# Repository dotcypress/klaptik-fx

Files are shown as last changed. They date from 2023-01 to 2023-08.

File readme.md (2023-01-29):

# klaptik-fx

Experimental Semigraphics Display.

klaptik-fx

## License

Licensed under either of

- Apache License, Version 2.0 ([LICENSE-APACHE](LICENSE-APACHE) or
  http://www.apache.org/licenses/LICENSE-2.0)
- MIT license ([LICENSE-MIT](LICENSE-MIT) or http://opensource.org/licenses/MIT)

at your option.

### Contribution

Unless you explicitly state otherwise, any contribution intentionally submitted
for inclusion in the work by you, as defined in the Apache-2.0 license, shall be
dual licensed as above, without any additional terms or conditions.

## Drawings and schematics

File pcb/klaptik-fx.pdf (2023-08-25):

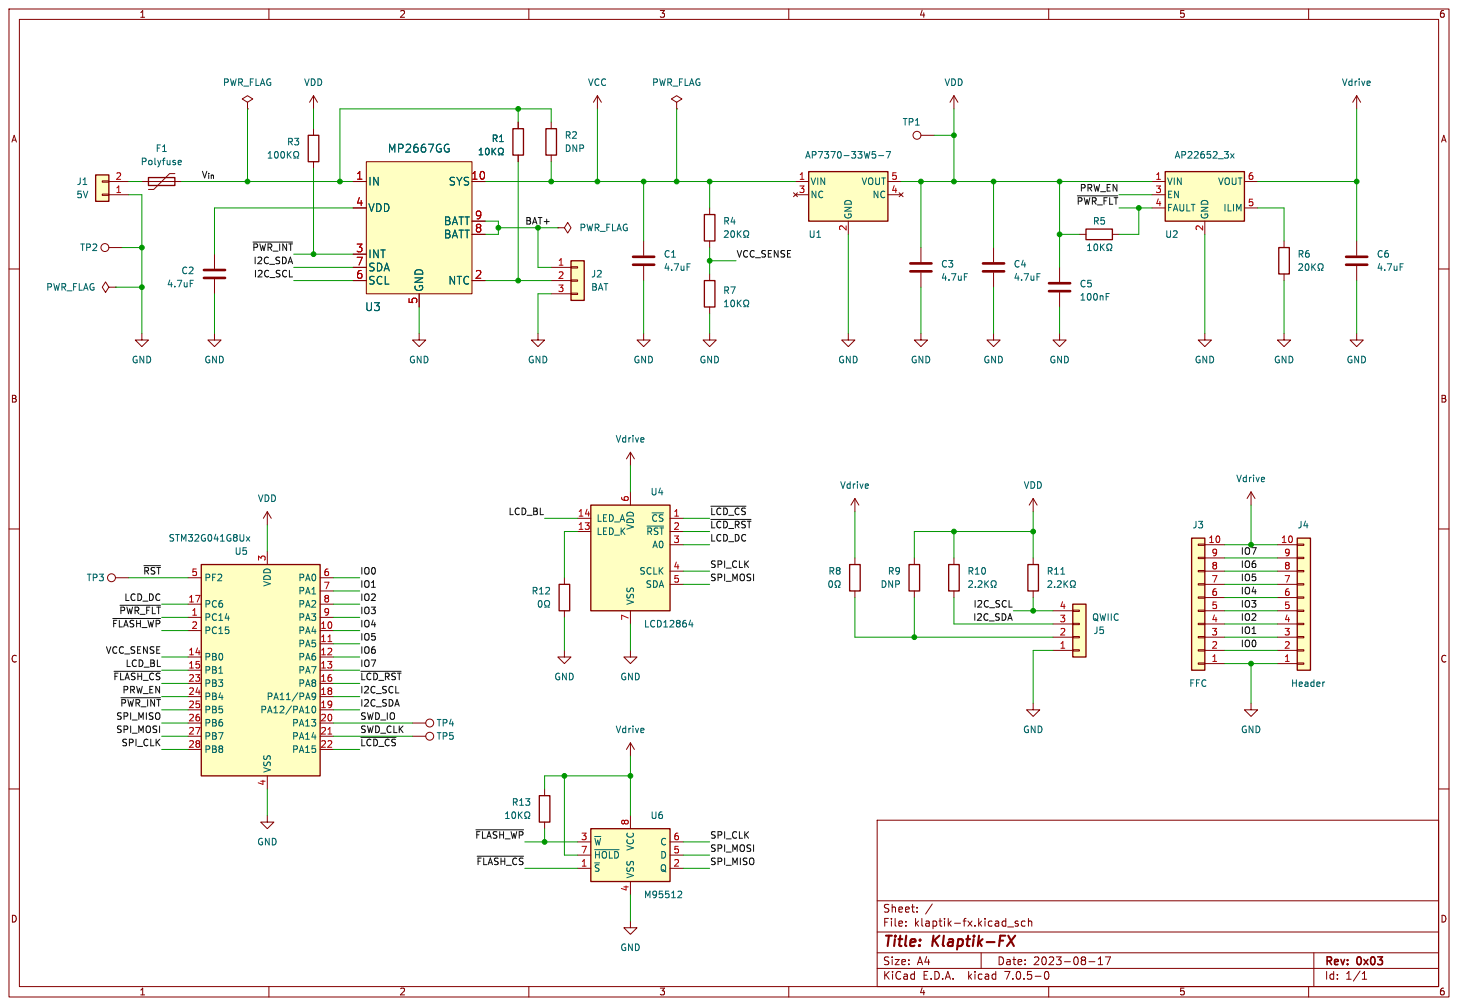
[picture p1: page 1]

5 SCL 6 SDA 7 BATT 8 BATT 9 U3 MP2667GG

5 SCL 6 SDA 7 BATT 8 BATT 9

Id: 1/1 Title: Klaptik-FX

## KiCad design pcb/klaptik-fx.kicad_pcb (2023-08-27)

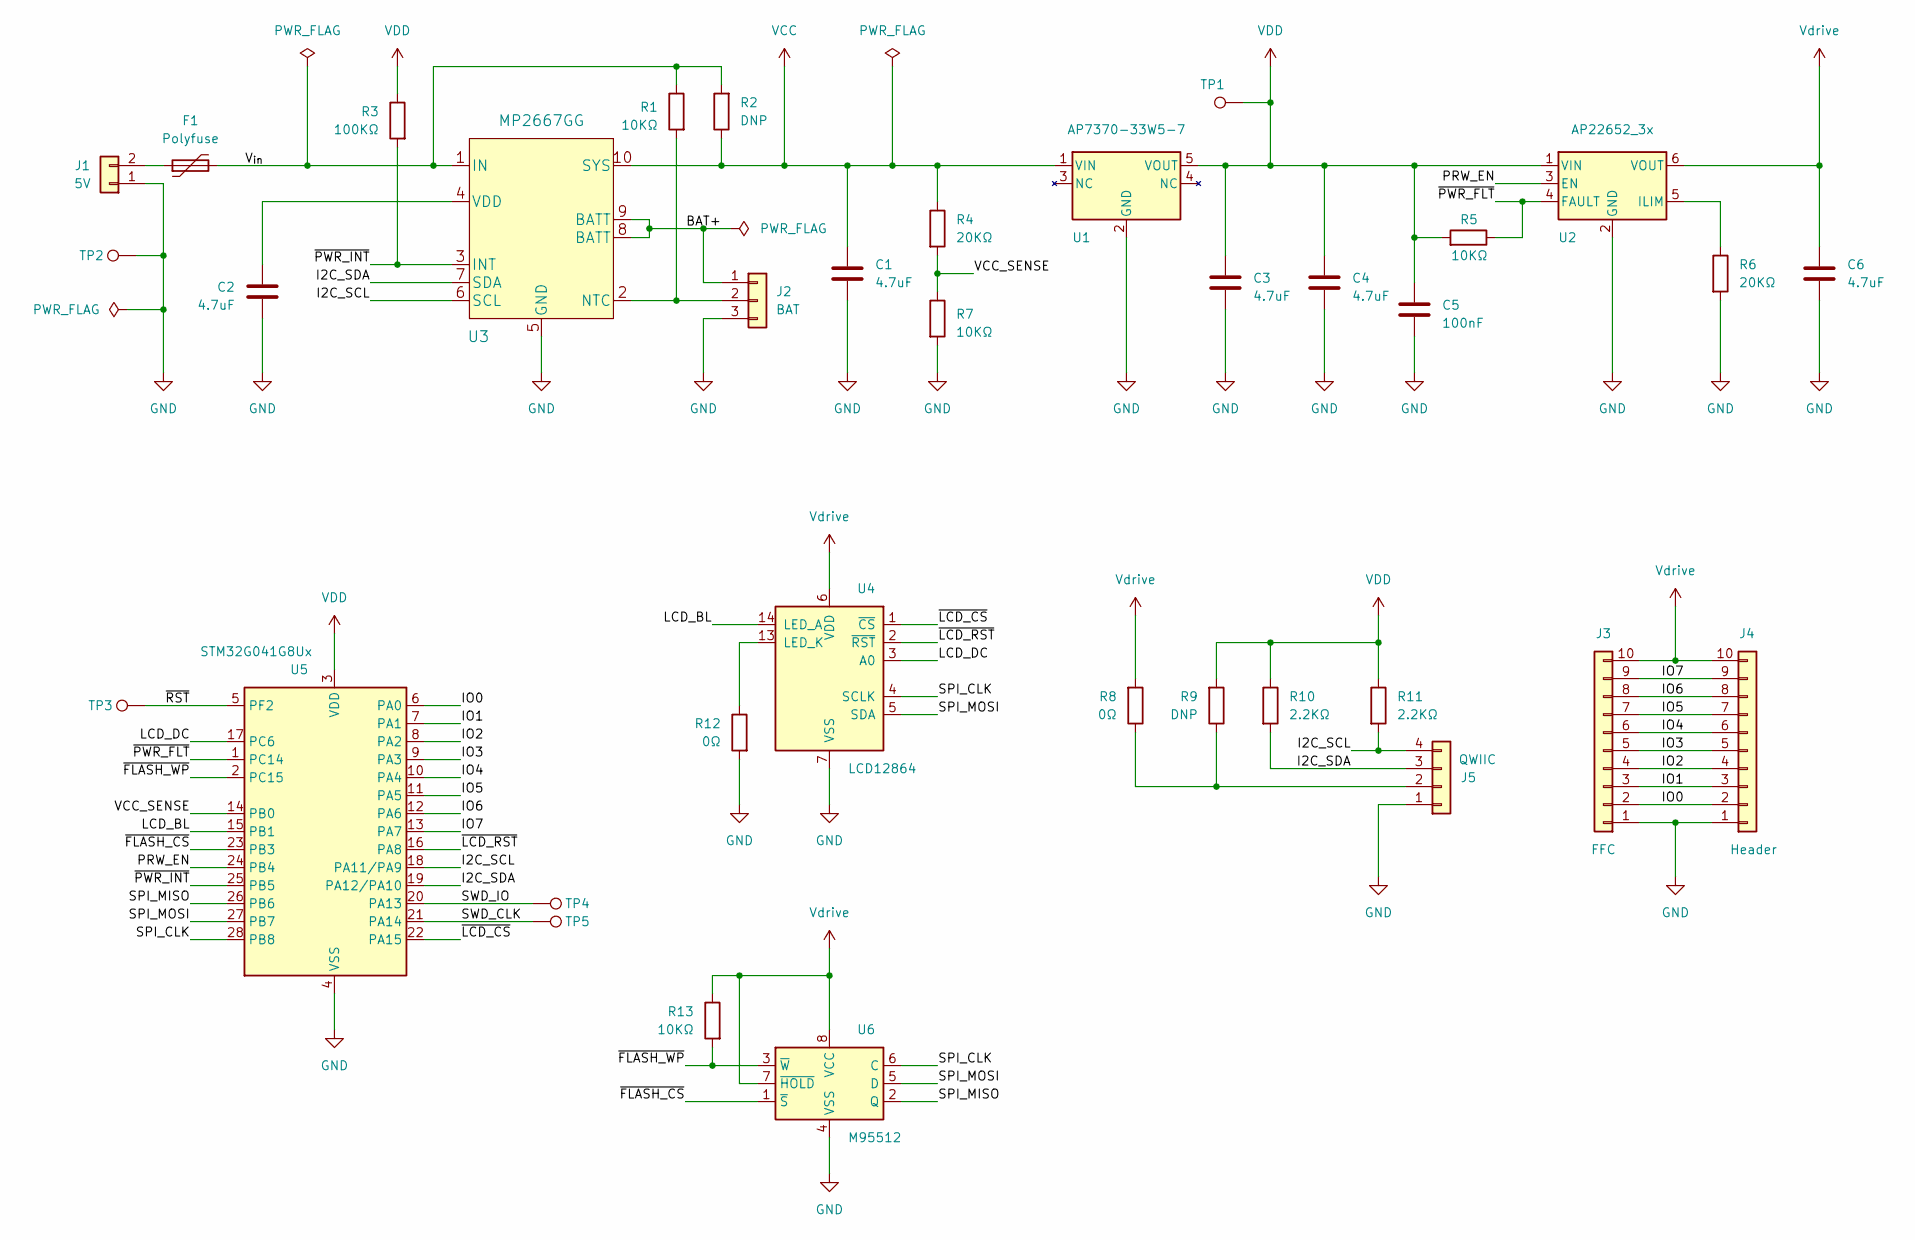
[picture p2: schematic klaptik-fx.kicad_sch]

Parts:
C1, C2, C3, C4, C6: 4.7uF; C_0402_1005Metric
C5: 100nF; C_0402_1005Metric
F1: Polyfuse; Fuse_0402_1005Metric
J1: 5V; PinHeader_1x02_P2.54mm_Vertical
J2: BAT; JST_SH_SM03B-SRSS-TB_1x03-1MP_P1.00mm_Horizontal
J3: FFC; Molex_54548-1071_1x10-1MP_P0.5mm_Horizontal
J4: Header; PinHeader_1x10_P1.27mm_Vertical
J5: QWIIC; JST_SH_SM04B-SRSS-TB_1x04-1MP_P1.00mm_Horizontal
R1, R5, R7, R13: 10KΩ; R_0402_1005Metric
R2, R9: DNP; R_0402_1005Metric
R3: 100KΩ; R_0402_1005Metric
R4, R6: 20KΩ; R_0402_1005Metric
R8, R12: 0Ω; R_0402_1005Metric
R10, R11: 2.2KΩ; R_0402_1005Metric
TP1: VDD; TestPoint_Pad_D1.0mm
TP2, TP3: GND; TestPoint_Pad_D1.0mm
TP4: SWD IO; TestPoint_Pad_D1.0mm
TP5: SWD CLK; TestPoint_Pad_D1.0mm
U1: AP7370-33W5-7; TSOT-23-5
U2: AP22652_3x; SOT-23-6
U3: MP2667GG; MP2667GG-xxxx-Z
U4: LCD12864; LCD_FPC_1x14_P0.80mm
U5: STM32G041G8Ux; QFN-28_4x4mm_P0.5mm
U6: M95512; TSSOP-8_4.4x3mm_P0.65mm

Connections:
/BAT+: J2.1, U3.8 (BATT), U3.9 (BATT)
/I2C_SCL: J5.4, R11.2, U3.6 (SCL), U5.18 (PA11/PA9)
/I2C_SDA: J5.3, R10.2, U3.7 (SDA), U5.19 (PA12/PA10)
/IO0: J3.2, J4.2, U5.6 (PA0)
/IO1: J3.3, J4.3, U5.7 (PA1)
/IO2: J3.4, J4.4, U5.8 (PA2)
/IO3: J3.5, J4.5, U5.9 (PA3)
/IO4: J3.6, J4.6, U5.10 (PA4)
/IO5: J3.7, J4.7, U5.11 (PA5)
/IO6: J3.8, J4.8, U5.12 (PA6)
/IO7: J3.9, J4.9, U5.13 (PA7)
/LCD_BL: U4.14 (LED_A), U5.15 (PB1)
/LCD_DC: U4.3 (A0), U5.17 (PC6)
/PRW_EN: U2.3 (EN), U5.24 (PB4)
/SPI_CLK: U4.4 (SCLK), U5.28 (PB8), U6.6 (C)
/SPI_MISO: U5.26 (PB6), U6.2 (Q)
/SPI_MOSI: U4.5 (SDA), U5.27 (PB7), U6.5 (D)
/SWD_CLK: TP5.1, U5.21 (PA14)
/SWD_IO: TP4.1, U5.20 (PA13)
/VCC_SENSE: R4.2, R7.1, U5.14 (PB0)
/V_{in}: F1.2, R1.1, R2.2, U3.1 (IN)
/~FLASH_CS: U5.23 (PB3), U6.1 (~S)
/~FLASH_WP: R13.2, U5.2 (PC15), U6.3 (~W)
/~LCD_CS: U4.1 (~CS), U5.22 (PA15)
/~LCD_RST: U4.2 (~RST), U5.16 (PA8)
/~PWR_FLT: R5.1, U2.4 (FAULT), U5.1 (PC14)
/~PWR_INT: R3.2, U3.3 (INT), U5.25 (PB5)
/~RST: TP3.1, U5.5 (PF2)
GND: C1.2, C2.2, C3.2, C4.2, C5.2, C6.2, J1.1, J2.3, J3.1, J4.1, J5.1, R6.2, R7.2, R12.2, TP2.1, U1.2 (GND), U2.2 (GND), U3.5 (GND), U4.7 (VSS), U5.4 (VSS), U6.4 (VSS)
unnamed: F1.1, J1.2
unnamed: J2.2, R1.2, U3.2 (NTC)
unnamed: J5.2, R8.1, R9.1
unnamed: R6.1, U2.5 (ILIM)
unnamed: C2.1, U3.4 (VDD)
unnamed: R12.1, U4.13 (LED_K)
VCC: C1.1, R2.1, R4.1, U1.1 (VIN), U3.10 (SYS)
VDD: C3.1, C4.1, C5.1, R3.1, R5.2, R9.2, R10.1, R11.1, TP1.1, U1.5 (VOUT), U2.1 (VIN), U5.3 (VDD)
Vdrive: C6.1, J3.10, J4.10, R8.2, R13.1, U2.6 (VOUT), U4.6 (VDD), U6.7 (~HOLD), U6.8 (VCC)

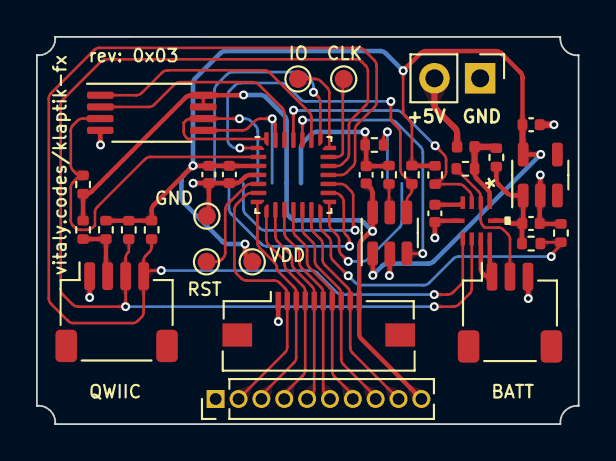
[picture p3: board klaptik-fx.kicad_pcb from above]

Board: 4 copper layers, 30.1 x 21.5 mm, 36 parts (1 on the bottom side), 38 nets.

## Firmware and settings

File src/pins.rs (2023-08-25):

use crate::hal::gpio::{gpioa::*, gpiob::*, gpioc::*};
use hal::gpio::*;
use hal::gpio::{DefaultMode, OpenDrain, Output, PushPull};
use hal::prelude::*;
use hal::rcc::Rcc;
use hal::stm32::*;

// SWD
pub type SwdIo = PA13<DefaultMode>;
pub type SwdClk = PA14<DefaultMode>;

// Qwiic I2C
pub type I2cClk = PA11<Output<OpenDrain>>;
pub type I2cSda = PA12<Output<OpenDrain>>;

// SPI
pub type SpiClk = PB8<DefaultMode>;
pub type SpiMiso = PB6<DefaultMode>;
pub type SpiMosi = PB7<DefaultMode>;

// Display
pub type LcdDC = PC6<Output<PushPull>>;
pub type LcdCS = PA15<Output<PushPull>>;
pub type LcdReset = PA8<Output<PushPull>>;
pub type LcdBacklight = PB1<DefaultMode>;

// EEPROM
pub type EepromCS = PB3<Output<PushPull>>;
pub type EepromWP = PC15<Output<PushPull>>;

// Power
pub type PowerEn = PB4<Output<PushPull>>;
pub type PowerInt = PB5<DefaultMode>;
pub type PowerFault = PC14<DefaultMode>;
pub type VccSense = PB0<DefaultMode>;

// GPIO
pub type Gpio0 = PA0<Input<Floating>>;
pub type Gpio1 = PA1<Input<Floating>>;
pub type Gpio2 = PA2<Input<Floating>>;
pub type Gpio3 = PA3<Input<Floating>>;
pub type Gpio4 = PA4<Input<Floating>>;
pub type Gpio5 = PA5<Input<Floating>>;
pub type Gpio6 = PA6<Input<Floating>>;
pub type Gpio7 = PA7<Input<Floating>>;

pub type I2cDev = hal::i2c::I2c<I2C2, I2cSda, I2cClk>;
pub type SpiDev = hal::spi::Spi<SPI2, (SpiClk, SpiMiso, SpiMosi)>;

pub struct Gpio {
    pub gpio0: Gpio0,
    pub gpio1: Gpio1,
    pub gpio2: Gpio2,
    pub gpio3: Gpio3,
    pub gpio4: Gpio4,
    pub gpio5: Gpio5,
    pub gpio6: Gpio6,
    pub gpio7: Gpio7,
}

pub struct Pins {
    // SWD
    pub swd_io: SwdIo,
    pub swd_clk: SwdClk,

    // Qwiic I2C
    pub i2c_clk: I2cClk,
    pub i2c_sda: I2cSda,

    // SPI
    pub spi_clk: SpiClk,
    pub spi_miso: SpiMiso,
    pub spi_mosi: SpiMosi,

    // Display
    pub lcd_dc: LcdDC,
    pub lcd_backlight: LcdBacklight,
    pub lcd_cs: LcdCS,
    pub lcd_reset: LcdReset,

    // EEPROM
    pub eeprom_cs: EepromCS,
    pub eeprom_wp: EepromWP,

    // Power
    pub power_en: PowerEn,
    pub power_int: PowerInt,
    pub power_fault: PowerFault,
    pub vcc_sense: VccSense,

    // GPIO
    pub gpio: Gpio,
}

impl Pins {
    pub fn new(gpioa: GPIOA, gpiob: GPIOB, gpioc: GPIOC, rcc: &mut Rcc) -> Self {
        let port_a = gpioa.split(rcc);
        let port_b = gpiob.split(rcc);
        let port_c = gpioc.split(rcc);

        Self {
            // SWD
            swd_io: port_a.pa13,
            swd_clk: port_a.pa14,

            // Qwiic I2C
            i2c_clk: port_a
                .pa11
                .set_speed(Speed::High)
                .into_open_drain_output_in_state(PinState::High),
            i2c_sda: port_a
                .pa12
                .set_speed(Speed::High)
                .into_open_drain_output_in_state(PinState::High),

            //SPI
            spi_clk: port_b.pb8.set_speed(Speed::VeryHigh),
            spi_miso: port_b.pb6.set_speed(Speed::VeryHigh),
            spi_mosi: port_b.pb7.set_speed(Speed::VeryHigh),

            // Display
            lcd_cs: port_a.pa15.into_push_pull_output_in_state(PinState::High),
            lcd_dc: port_c.pc6.into(),
            lcd_reset: port_a.pa8.into(),
            lcd_backlight: port_b.pb1,

            // EEPROM
            eeprom_cs: port_b.pb3.into_push_pull_output_in_state(PinState::High),
            eeprom_wp: port_c.pc15.into_push_pull_output_in_state(PinState::High),

            power_en: port_b.pb4.into(),
            power_int: port_b.pb5,
            power_fault: port_c.pc14,
            vcc_sense: port_b.pb0,

            // GPIO
            gpio: Gpio {
                gpio0: port_a.pa0.into(),
                gpio1: port_a.pa1.into(),
                gpio2: port_a.pa2.into(),
                gpio3: port_a.pa3.into(),
                gpio4: port_a.pa4.into(),
                gpio5: port_a.pa5.into(),
                gpio6: port_a.pa6.into(),
                gpio7: port_a.pa7.into(),
            },
        }
    }
}

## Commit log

2023-01-29 stm32c0 port
2023-01-29 pcb rev 0x02
    [klaptik-fx.kicad_pcb]
2023-04-23 add bom
    [klaptik-fx.kicad_pcb, klaptik-fx.kicad_sch]
2023-08-18 rev 0x03
    [klaptik-fx.kicad_pcb, klaptik-fx.kicad_sch]
2023-09-05 update schematics
    [klaptik-fx.kicad_sch]
